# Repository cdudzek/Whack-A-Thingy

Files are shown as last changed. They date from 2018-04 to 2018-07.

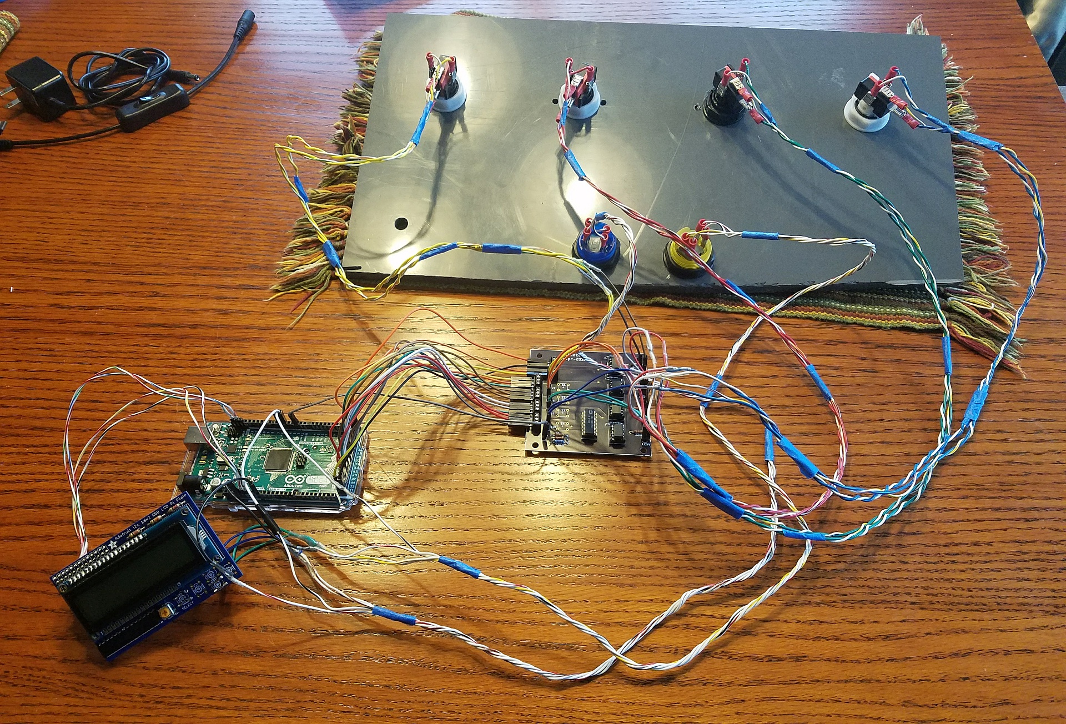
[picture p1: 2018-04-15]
Photos/Test_Wired.jpg

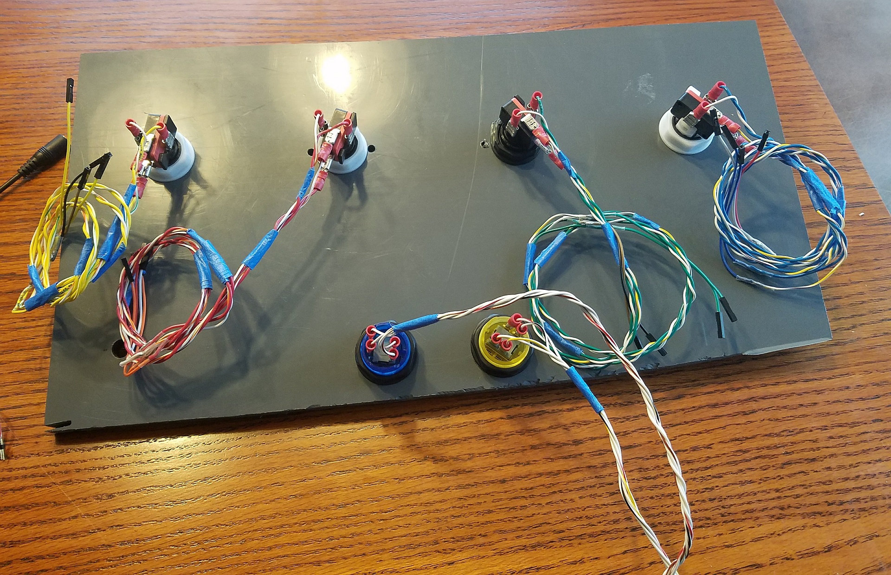
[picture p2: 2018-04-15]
Photos/Test_Buttons.jpg

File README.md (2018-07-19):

# Whack-A-Thingy
Whack-A-Thingy Multi-Gameboard

## Introduction
Whack-A-Thingy is a multi-game hardware and software platform built on an Arduino Mega 2560 controller.

This GitHub repo is a work in progress, as I am currently building the first game board as we speak. Photos, assembly guide, and gameplay will be added when available.

### Game Board
The gameboard consists of the following features:
* Arduino Mega 2560 controller
* RGB-Backlit LCD 16x2 display for menus, messages, and scores
* Two 30mm arcade buttons for menu controls (Select/Start)
* Eight 100mm colored LED-backlit arcade buttons for game targets
* Custom designed PCB to connect target buttons with Arduino controller
* Wooden base frame

### Games Included
* Whack-A-Thingy - Whack-A-Mole clone using up to 8 target buttons, with selectable speed/difficulty
* Simon Sez - Simon Says clone using up to 8 target buttons. The game runs until you get one wrong!
* Reaction Time - See how fast you can hit the button after it lights. Selectable up to 8 target buttons to increase the difficulty.
* Button Test - Check that all buttons can light up, can respond to hardware interrupts, and can respond to hardware polling

## Game Board Design
All hardware, software, and electronics used to create the board are (or soon will be) included in the repository.

The [Bill of Materials](https://github.com/cdudzek/Whack-A-Thingy/blob/master/Documents/Bill%20of%20Materials%20with%20Costs.xlsx) lists most of the electronics and hardware used in the build. The total cost of the build (not including some power tools and soldering equipment) was less than US$300. Many thanks to Adafruit for their awesome part selection at cheap prices!

### Arduino Mega and Source Code
The GameBoard folder contains all of the Arduino source files to build the game. 

The size of the code, memory footprint, and required I/Os for all of the game buttons required the use of an Arduino Mega controller (instead of an Uno-compatible). It is possible the game could be adpated to other controllers or platforms, but this is the only one I have tested with. 

#### Prerequisites
* The [Adafruit RGB LCD Library](https://github.com/adafruit/Adafruit-RGB-LCD-Shield-Library) for Arduino is required to communicate with the [I2C RGB LCD Shield for Arduinos](https://www.adafruit.com/product/716).

### Physical Board Design
The game board and components were designed in Solidworks. The CAD folder contains the original Solidworks models and assembly, as well as standard STEP files. The PDF file shows the components and assemblies.

### Electronics
The project design includes a custom-designed circuit board to interface from the Arduino to the big target buttons. The board was designed in Fritzing, and includes all of the necessary files to send the board out for fabrication. 

Each PCB controls 4 target buttons, so 2 are used for the 8 total game buttons. The price to have 3 boards fabricated with [OSHPark](https://oshpark.com/) was less than US$50.

I will be creating a Fritzing model for the custom PCBs, and plan to provide a full Fritzing assembly including the Arduino, custom PCBs, buttons, and all wiring. 

## License

This project is licensed under the Apache 2.0 License - see the [LICENSE](LICENSE) file for details

## Acknowledgments
This project is 100% custom designed (hardware, software, and electronics), but I got the original idea from the [Whac-A-Mole](https://www.hackster.io/WT040/whac-a-mole-button-edition-a2d391) project on [Hackster.io](https://hackster.io).

I would like to give a shout out to the awesome folks at [Adafruit](https://www.adafruit.com/) for their awesome product selection (including the massive [100mm arcade buttons](https://www.adafruit.com/product/1185)!), tutorials, code libraries and examples, and everything else they do. They are an inspiration. (I am in no way affiliated with Adafruit, just a very happy repeat customer.)

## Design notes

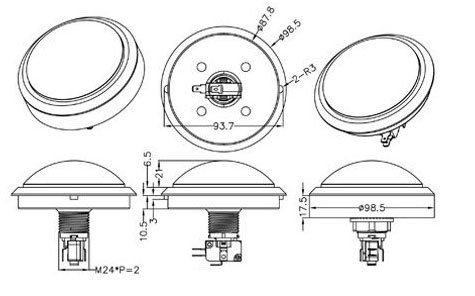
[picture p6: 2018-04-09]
Documents/Specifications/100mm Button Adafruit#1185.jpg

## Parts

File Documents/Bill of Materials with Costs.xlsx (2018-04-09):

Game Board
Bill of Materials with costs
Quantities per total project
Description | Vendor | Vendor P/N | US$ each | Qty | Ext. Price
0.1" Pitch Terminal Block, 2 pin | Adafruit | 2138 | $0.86 | 4 | $3.44
0.1" Pitch Terminal Block, 3 pin | Adafruit | 2136 | $1.13 | 8 | $9.04
100mm Arcade Button, Blue | Adafruit | 1189 | $9.95 | 2 | $19.90
100mm Arcade Button, Green | Adafruit | 1188 | $9.95 | 2 | $19.90
100mm Arcade Button, Red | Adafruit | 1185 | $9.95 | 2 | $19.90
100mm Arcade Button, Yellow | Adafruit | 1186 | $9.95 | 2 | $19.90
14-Pin DIP socket | Digikey | A401-ND | $1.56 | 2 | $3.12
2-Input AND Gate | Digikey | 296-1606-5-ND | $0.47 | 2 | $0.94
30mm Arcade Button, Blue | Adafruit | 3490 | $2.50 | 1 | $2.50
30mm Arcade Button, Yellow | Adafruit | 3488 | $2.50 | 1 | $2.50
8-Pin DIP socket | Digikey | A120347-ND | $0.16 | 8 | $1.28
9V 1000mA Power Adapter | Adafruit | 63 | $6.95 | 1 | $6.95
Arduino Mega 2560 Rev 3 | Arduino.cc | A000067 | $38.50 | 1 | $38.50
DC Power Cable 2.1mm | Adafruit | 743 | $2.50 | 1 | $2.50
Fabricated PC Boards, 80x80mm, Order/3 | OSHPark | Custom Order | $49.60 | 1 | $49.60
In-line Power Switch | Adafruit | 1125 | $2.50 | 1 | $2.50
Male Break-Away Pins, 1x36, Pack/10 | Adafruit | 392 | $4.95 | 1 | $4.95
Mega Protoshield | Adafruit | 192 | $14.95 | 1 | $14.95
Optoisolator | Digikey | 6N139-ND | $1.46 | 8 | $11.67
Panel Mount 2.1mm DC Barrel Jack | Adafruit | 610 | $2.95 | 1 | $2.95
Panel Mount USB-B Cable | Adafruit | 907 | $3.95 | 1 | $3.95
Piezo Buzzer with mount and wires | Adafruit | 1739 | $0.95 | 1 | $0.95
Resistor 10k 5% | Digikey | 10KQBK-ND | $0.06 | 10 | $0.59
Resistor 220R 5% | Digikey | 220QBK-ND | $0.06 | 12 | $0.71
RGB LCD + Keypad kit | Adafruit | 1109 | $24.95 | 1 | $24.95
Tactile Button Switch, Pack/20 | Adafruit | 367 | $2.50 | 1 | $2.50
Various LEDs (for testing and customization) | Adafruit | 300 | $8.00 | 1 | $8.00
Total |  | 27 |  |  | $278.64
Items not listed:
Jumper and interconnect wires
Crimp connectors for switches and lights
Wood, Acrylic or other Game Board frame and Legs
Soldering iron and other solder tools
Wire strippers and other hand tools
Generic USB A-B cables for Arduino
Screws and other assembly and mounting hardware
Digital Multimeter and other test tools
Tools for cutting/finishing frame pieces

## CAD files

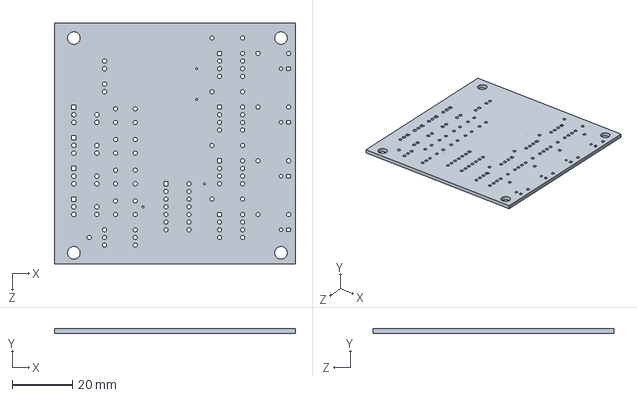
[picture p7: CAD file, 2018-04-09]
Fritzing/Target PCB/PCB_04-02-2018.SLDPRT
79.9 x 1.60 x 79.9 mm

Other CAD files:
Fritzing/Target PCB/Target4x_PCB_04-02-2018 v1.iges
Fritzing/Target PCB/PCB_04-02-2018.IGS

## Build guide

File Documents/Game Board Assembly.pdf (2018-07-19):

# Game Board Assembly

14 April 2018, Chad Dudzek

## Test Assembly

On 14 April I assembled the game board for testing on a temporary panel. It included four of the eight target buttons, the two menu buttons, one of the two custom circuit boards, the Arduino Mega controller, and the RGB LCD panel.

See the videos in the repository for the first power-on and the button test. The select/start buttons were attached to the wrong Arduino pins, so the yellow Select button did not light up on the first power-up.

Please note that in the video the 100mm buttons are not very bright because I was only pushing 5V from the Arduino through the LEDs, which are rated to 12V. On the final board assembly I will pull 9V directly from the power supply for those lights instead of powering them through the Arduino pins; this will also reduce the power draw through the Arduino board.

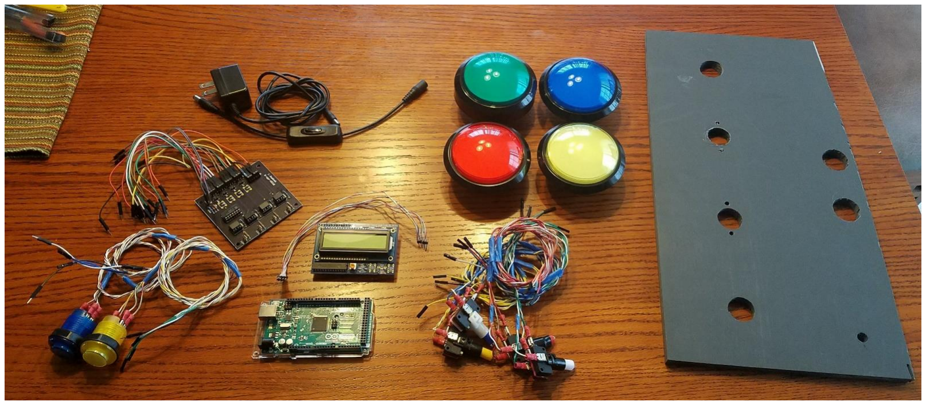
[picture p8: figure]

## Parts List

Arduino Mega 2560 Rev 3

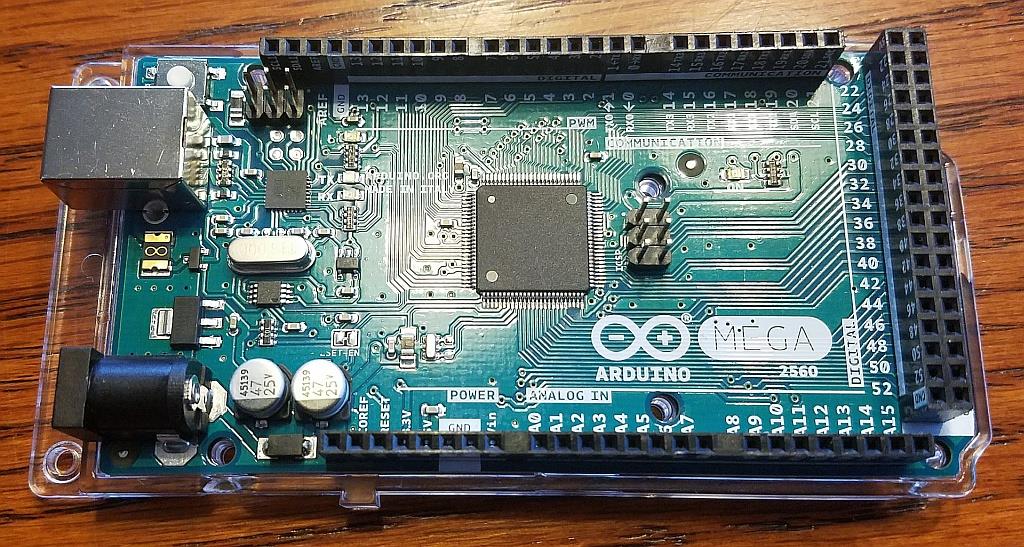
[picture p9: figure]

One of the 100mm target buttons with a switch and light attached and wired

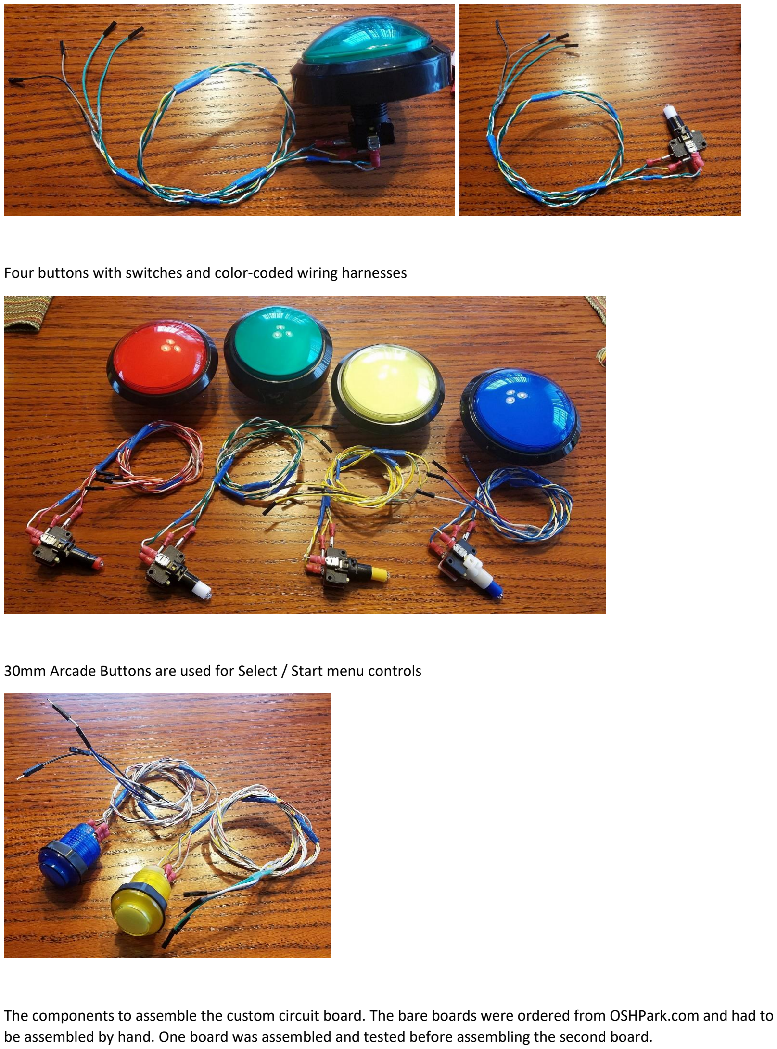
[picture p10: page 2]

Four buttons with switches and color-coded wiring harnesses

30mm Arcade Buttons are used for Select / Start menu controls

The components to assemble the custom circuit board. The bare boards were ordered from OSHPark.com and had to be assembled by hand. One board was assembled and tested before assembling the second board.

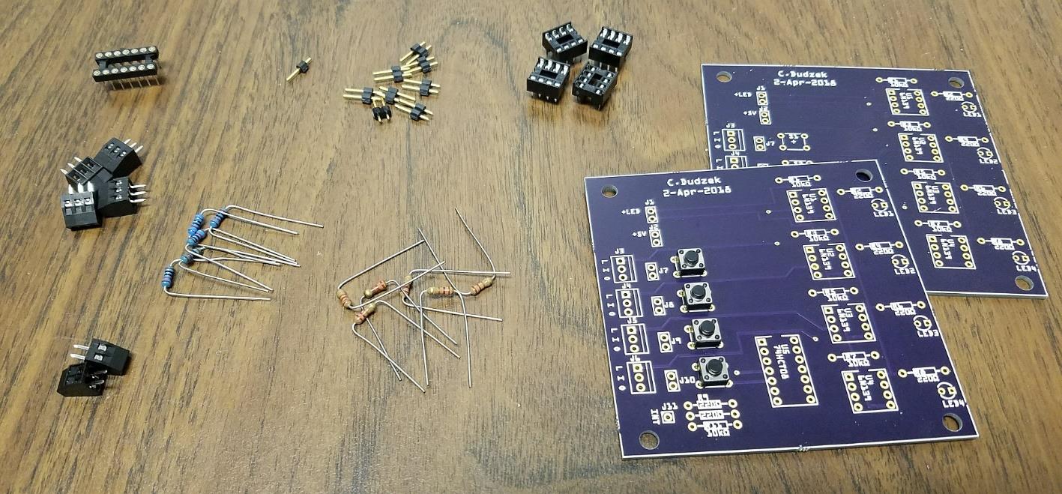
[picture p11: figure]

The assembled board, and with the cables attached which connect to the Arduino. For the test build I used a 74HCT21 (4-input AND gate) in U5 instead of the 74HCT08 (2x 2-input AND gate). The rest of the circuit is the same, but the 74HCT21 combines all 4 inputs into a single output, and can be used as a drop-in replacement in this board with no other changes.

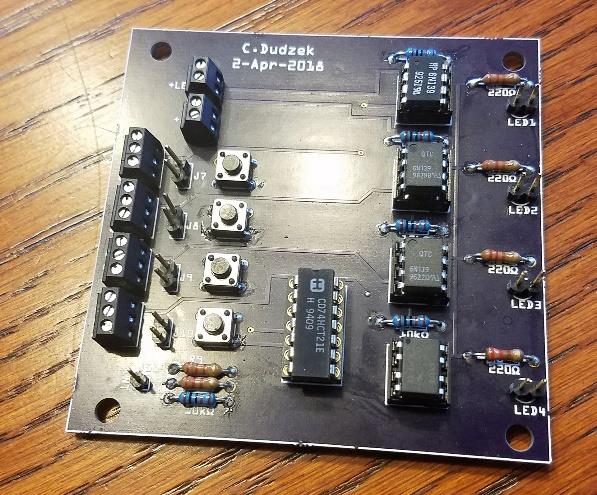
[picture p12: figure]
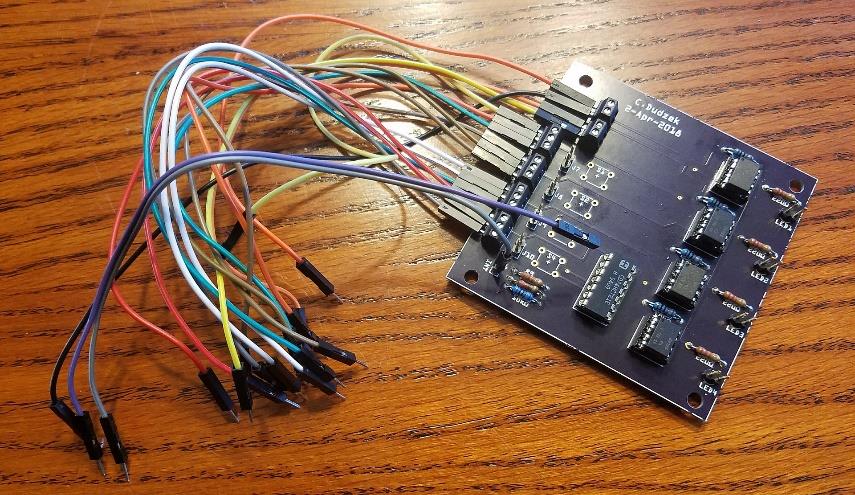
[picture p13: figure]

After soldering up the first board and testing it, I discovered I had a trace on the wrong side and it shorted to a 5V input. The trace for U4 Pin 3 (grounds to enable LED4) crossed the trace to U5 Pin 14, which is the +5V supply. Whoops! The trace had to be cut on the bottom of the board where the traces intersected, and a jumper wire soldered from J6 Pin 1 to U4 Pin 3.

TODO: Add photo of jumper wire

A 9V/1A power supply and switch from Adafruit are used to power the whole game board.

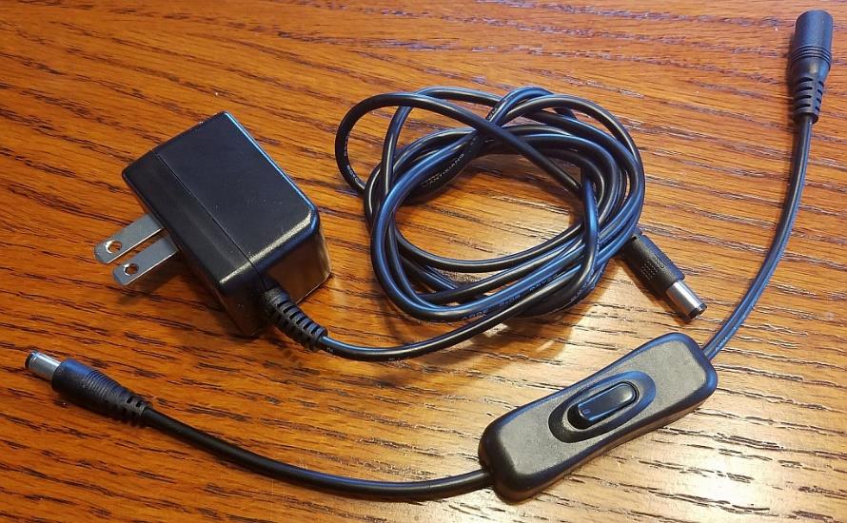
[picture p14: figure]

The Adafruit RGB LCD Pi Plate. This is designed to attach to the top of a Raspberry Pi, but a wiring harness was created to attach to the Arduino. Only the 5VDC, Ground, and I2C wires are needed.

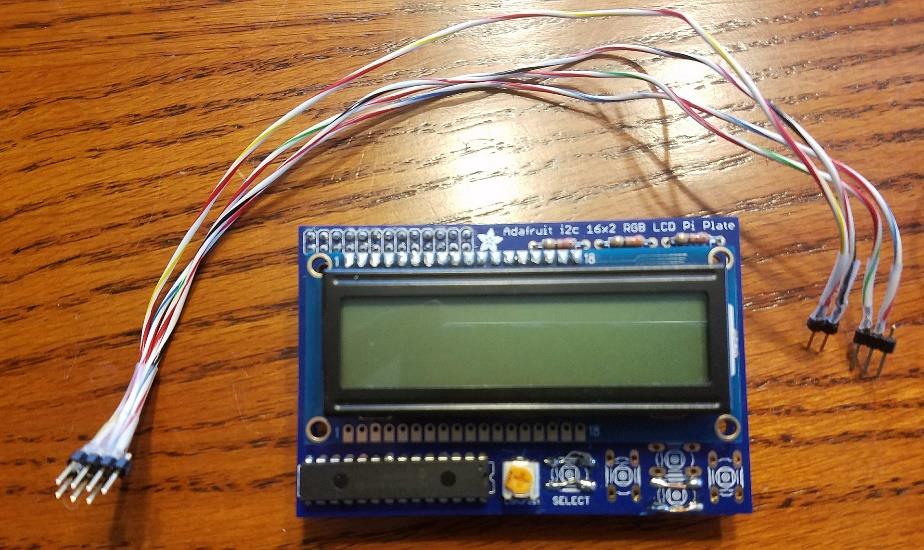
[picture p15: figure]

A test panel was used to mount all of the control and target buttons for initial testing. One inch holes were drilled for the four target buttons and 1-1/8” holes were drilled for the 30mm control buttons. The LCD, Arduino, and circuit boards were not mounted for testing.

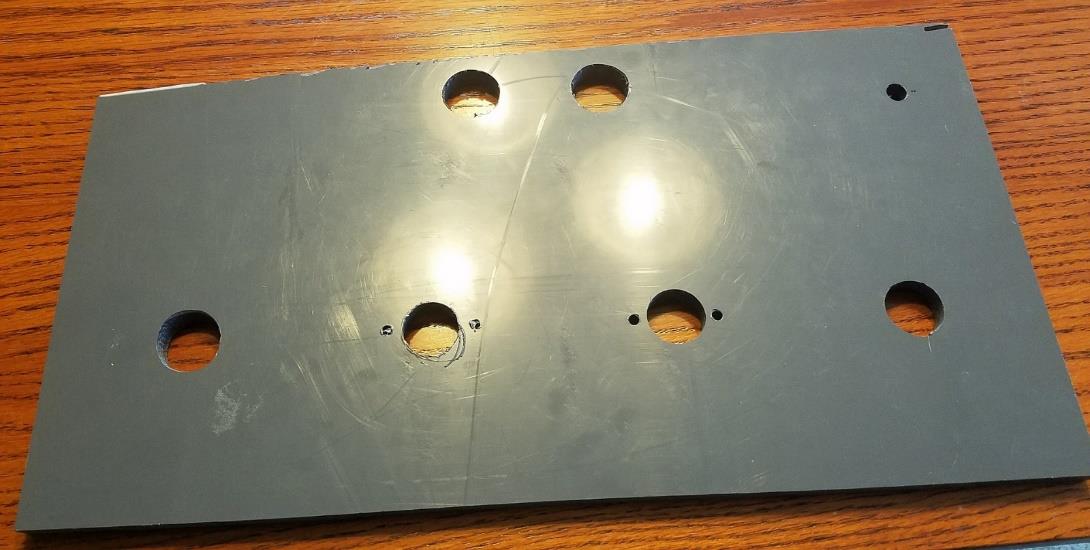
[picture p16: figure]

With the buttons mounted

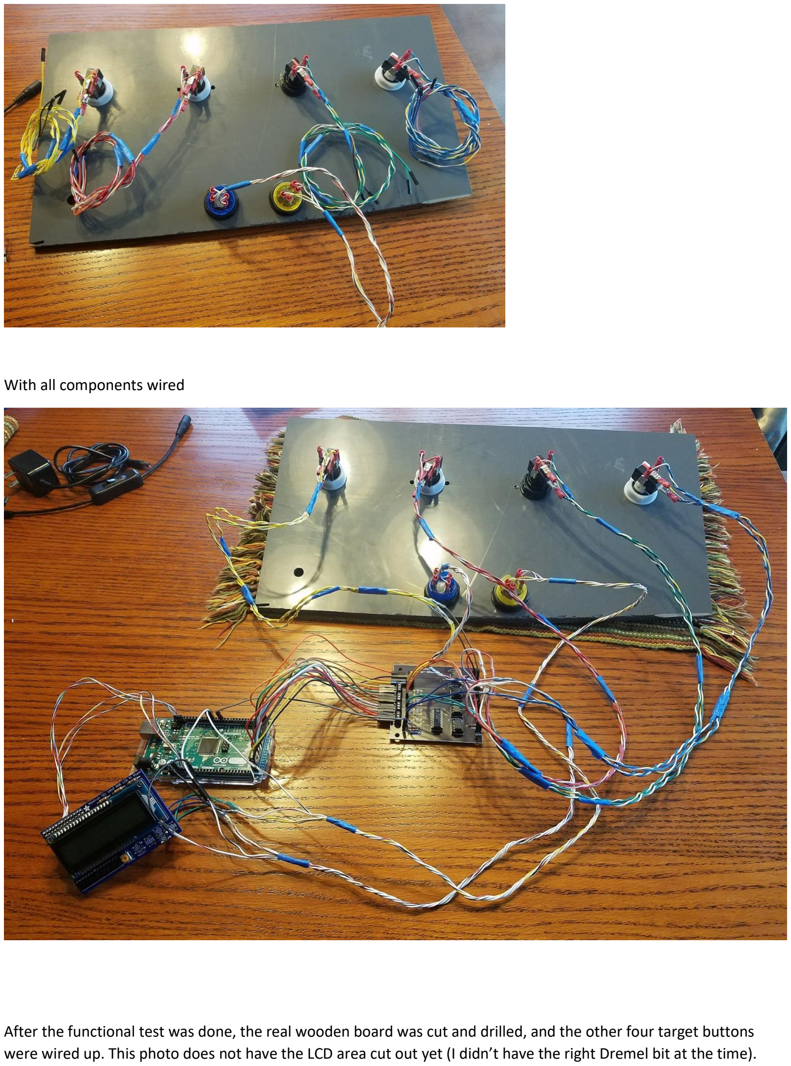
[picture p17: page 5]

With all components wired

After the functional test was done, the real wooden board was cut and drilled, and the other four target buttons were wired up. This photo does not have the LCD area cut out yet (I didn’t have the right Dremel bit at the time).

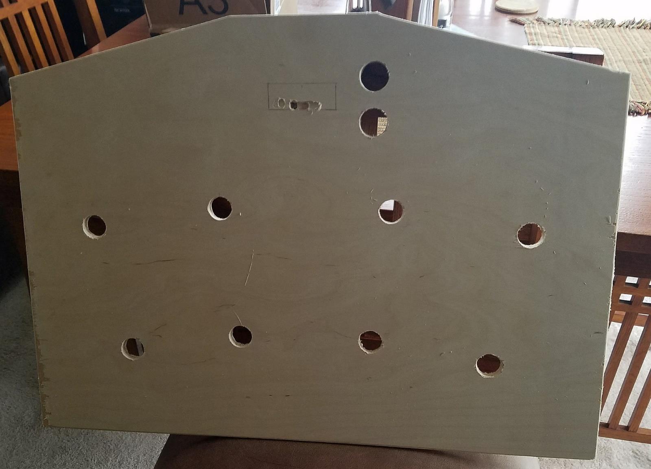
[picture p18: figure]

The board is a ½” (12.5mm) layered birch wood. I bought the green 100mm target buttons from Adafruit, and I was able to mount the button on the board with the extra backing disc to have a solid-looking body. However, the other colored buttons were bought on Amazon (only because they were out of stock at Adafruit) and were not long enough to fit with the backing disc so they had to be mounted without it. The product images and dimension drawing on Amazon were IDENTICAL to the ones on Adafruit, but the buttons were indeed not the same product. The shaft length was not specified on either site, so I do not know which one was technically correct.

TODO: Side view of board with button threads

## Wiring

This is the top view of the PC Board (with the corrected trace). All components are labeled, including the resistor values. Yellow lines are traces on the top of the board, and orange lines are traces on the bottom of the board.

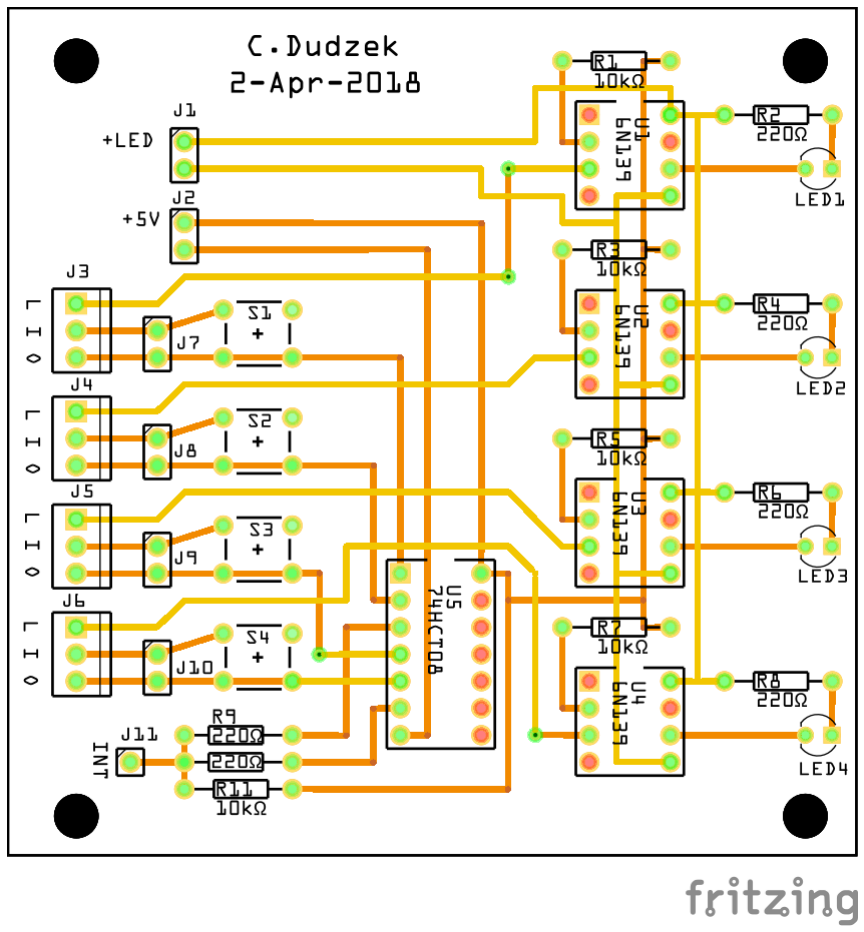
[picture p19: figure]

Connector J1 is input power for the target button LEDs. The 100mm buttons from Adafruit are 12V capable, and the U1-U4 chips are optoisolators (they work like relays) to allow the 12V to be used without frying your Arduino board. Pin 1 is up to +12V, and pin 2 is ground.

Chips U1-U4 will ground pin 6 to turn on the LEDs. Two-pin headers are soldered into the LED1-LED4 pins instead of LEDs so the target button LEDs can be attached.

Connector J2 is the +5V power for the ICs. U5 is powered directly on pin 14. Resistors R1, R3, R5, and R7 are used to drop the voltage to 1.4V for the optoisolator triggers on pin 2 of each chip.

Connectors J3-J6 are the controls for each target, which connect to the Arduino. Note that connectors have the pins labeled L-I-O next to each connector. These are “LED on”, “Switch Input”, and “Switch Output”.

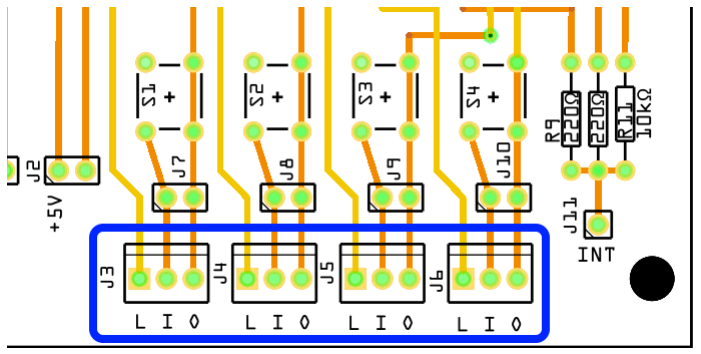
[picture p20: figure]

When the LED (L) pin on each connector is grounded, the LED for that target will be lit.

Connectors J7-J10 are headers to the target button switches. They short connect the Input (I) and Output (O) pins of each target when pressed. Switches S1-S4 are entirely optional to populate. They are sized for the 6x6mm tactile switches from Adafruit. They are handy for testing the circuit without having to wire up the 100mm target buttons but are not required for proper game operation.

Chip U5 is the 4-input AND gate to output an interrupt signal when an enabled target button is pressed. When an Input (I) pin on J3-J6 is grounded, that target button is enabled. The AND gate isolates the buttons from each other, so only an enabled button can trigger the interrupt or be read from the Output (O) pin.

Pin J11 is the interrupt pin to signal the Arduino that an enabled target has been pressed. This is used especially for the Whack-A-Mole game to instantly signal the program that an active mole has been whacked.

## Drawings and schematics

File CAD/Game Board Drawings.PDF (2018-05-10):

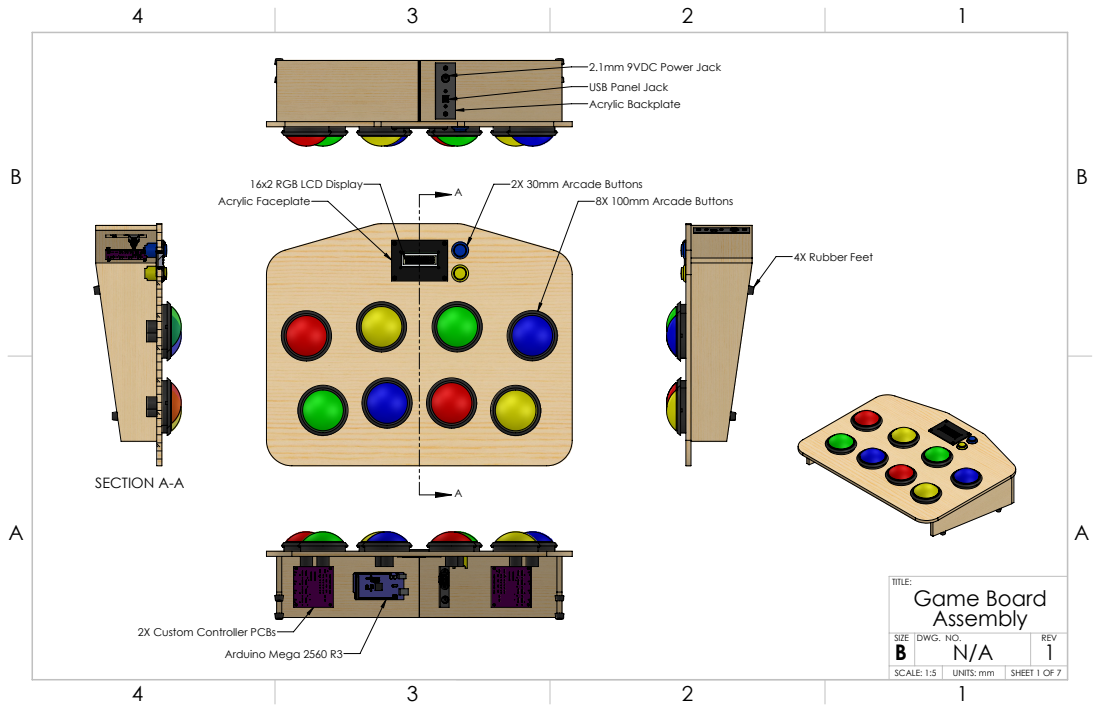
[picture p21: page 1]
16x2 RGB LCD Display; 2X 30mm Arcade Buttons; Acrylic Faceplate; 8X 100mm Arcade Buttons; Arduino Mega 2560 R3; SECTION A-A; 4X Rubber Feet; Game Board

2.1mm 9VDC Power Jack
USB Panel Jack
Acrylic Backplate

2X Custom Controller PCBs

SIZE B | DWG. NO. N/A | REV 1

SCALE: 1:5 | UNITS: mm | SHEET 1 OF 7

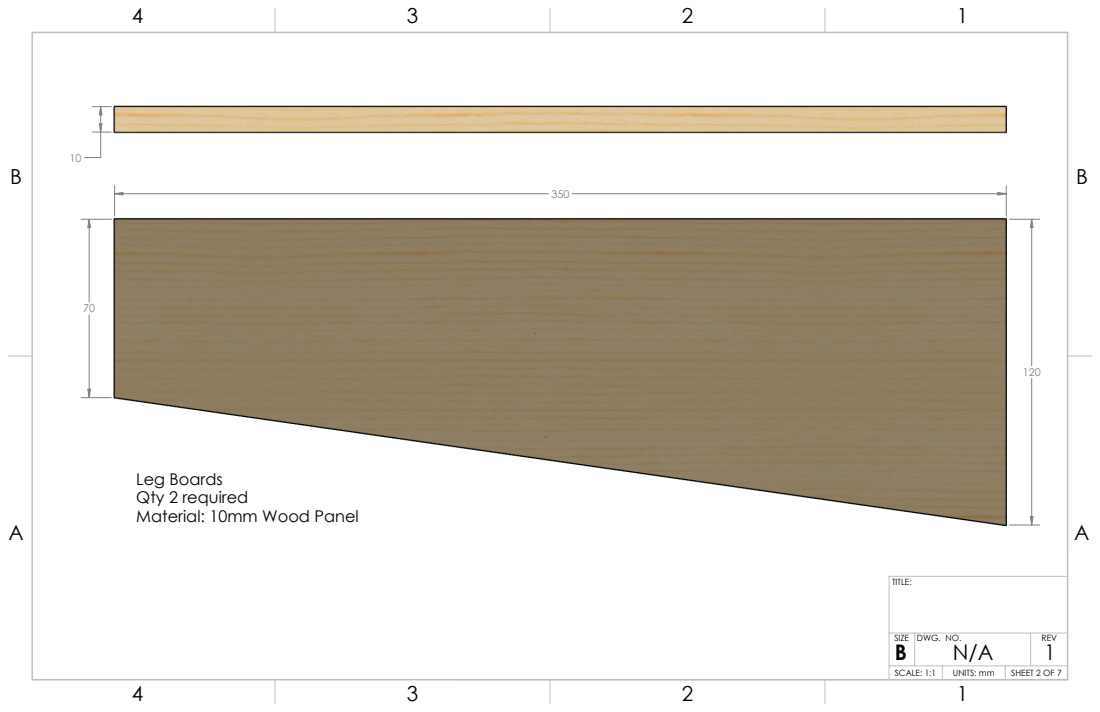
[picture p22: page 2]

Leg Boards
Qty 2 required
Material: 10mm Wood Panel

SIZE B | DWG. NO. N/A | REV 1

SCALE: 1:1 | | SHEET 2 OF 7

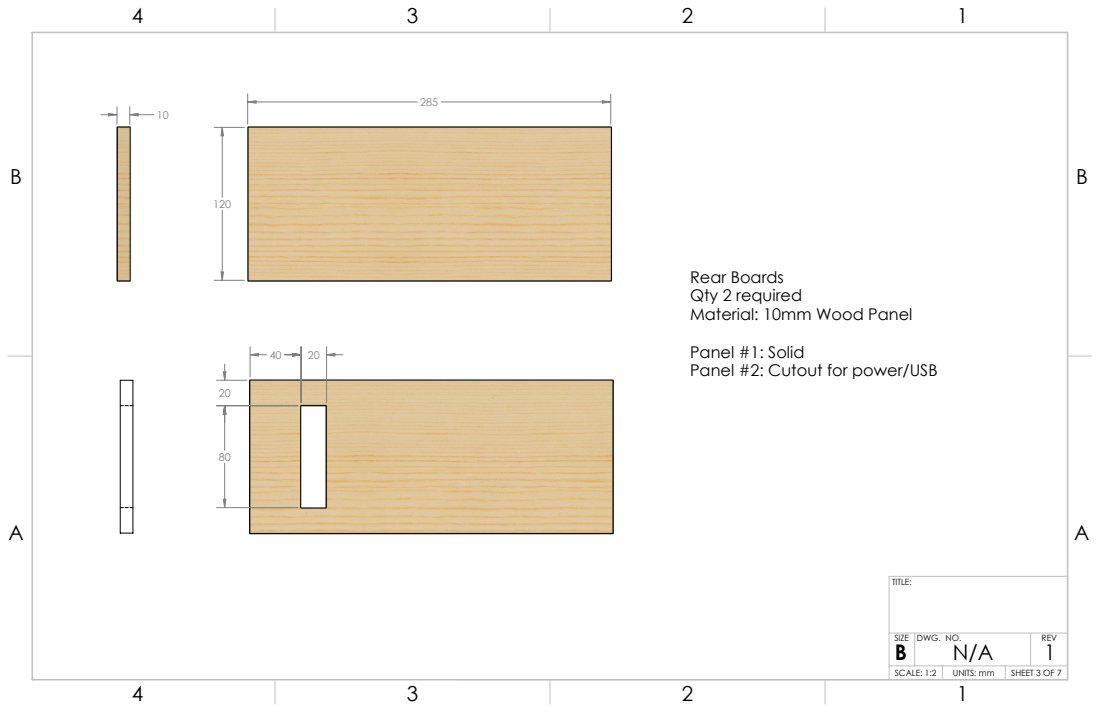
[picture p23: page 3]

Rear Boards
Qty 2 required
Material: 10mm Wood Panel
Panel #1: Solid
Panel #2: Cutout for power/USB

SIZE B | DWG. NO. N/A | REV 1

SCALE: 1:2 | | SHEET 3 OF 7

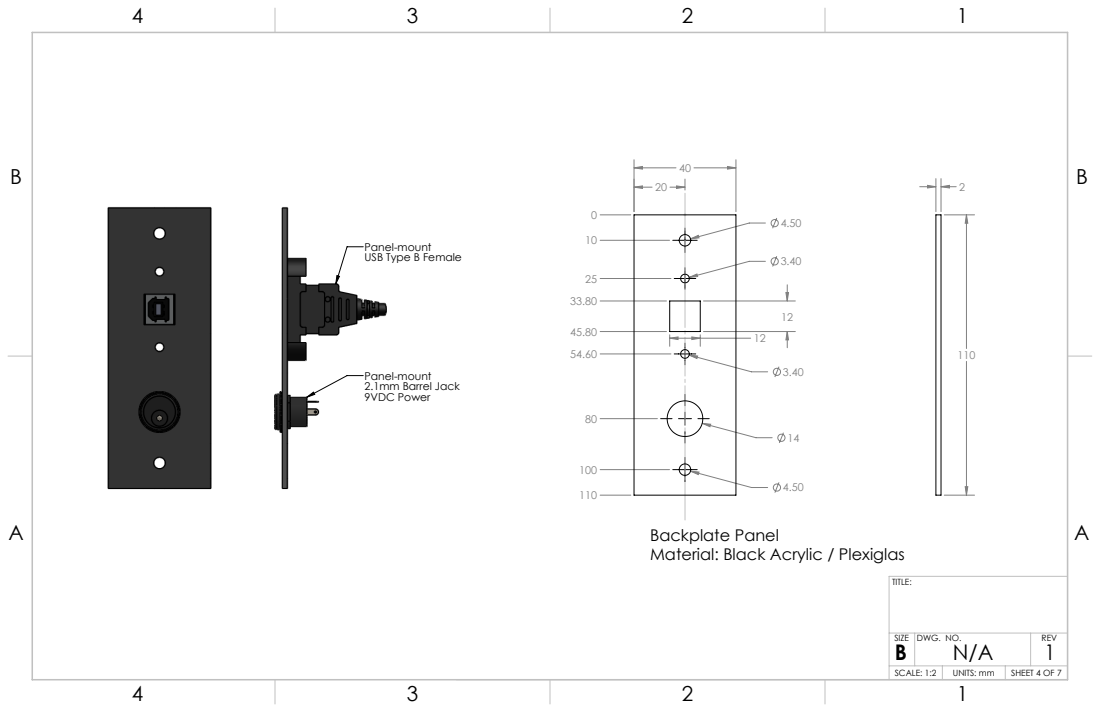
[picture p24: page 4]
2.1mm Barrel Jack 9VDC Power; DWG. NO.; REV

Panel-mount
USB Type B Female

Backplate Panel
Material: Black Acrylic / Plexiglas

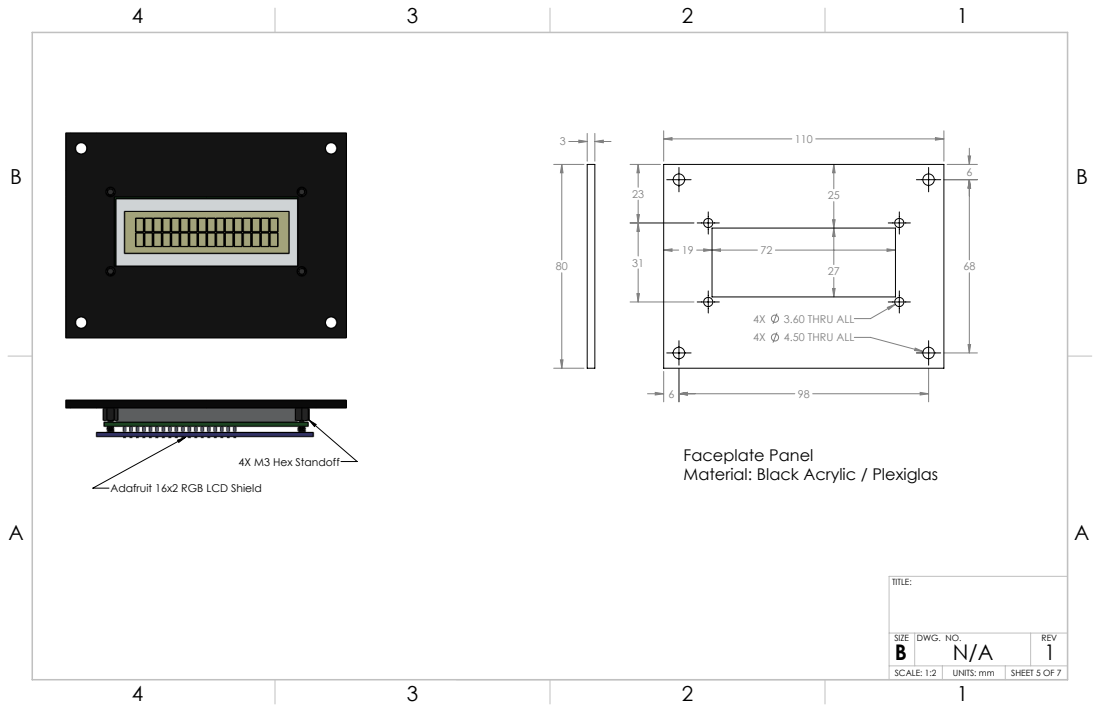
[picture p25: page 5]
4X M3 Hex Standoff; 3.60 THRU ALL; 4.50 THRU ALL; DWG. NO.; REV

Faceplate Panel
Material: Black Acrylic / Plexiglas

Adafruit 16x2 RGB LCD Shield

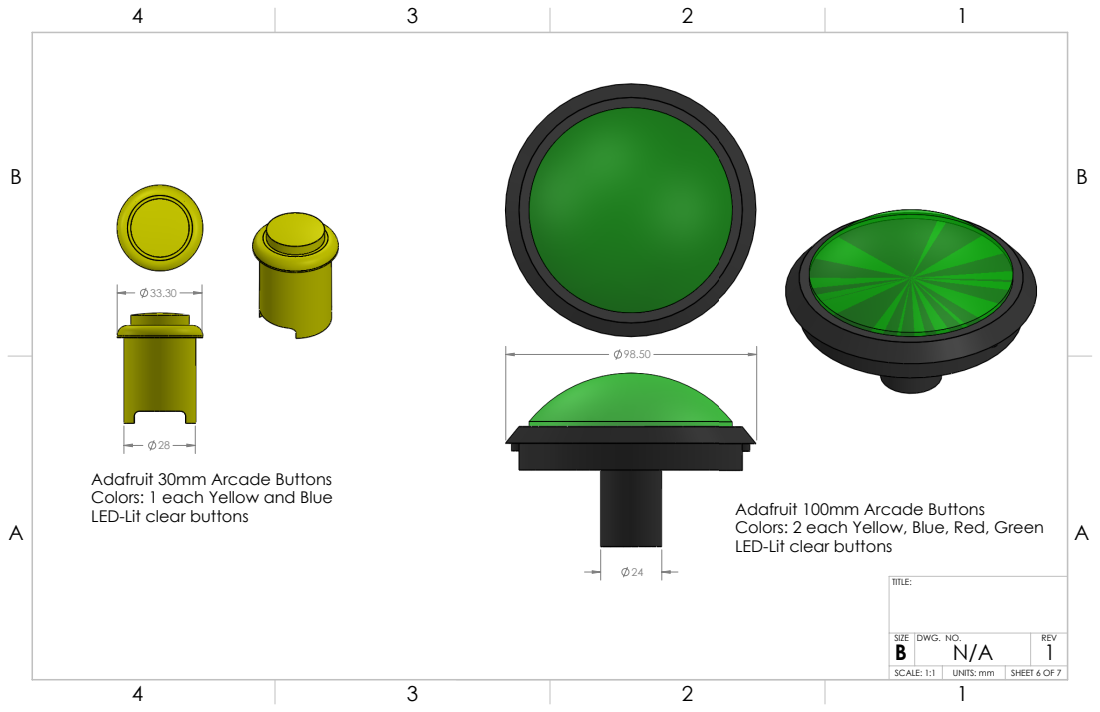
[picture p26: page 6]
LED-Lit clear buttons; Adafruit 100mm Arcade Buttons

Adafruit 30mm Arcade Buttons
Colors: 1 each Yellow and Blue

Colors: 2 each Yellow, Blue, Red, Green
LED-Lit clear buttons

SIZE B | DWG. NO. N/A | REV 1

SCALE: 1:1 | | SHEET 6 OF 7

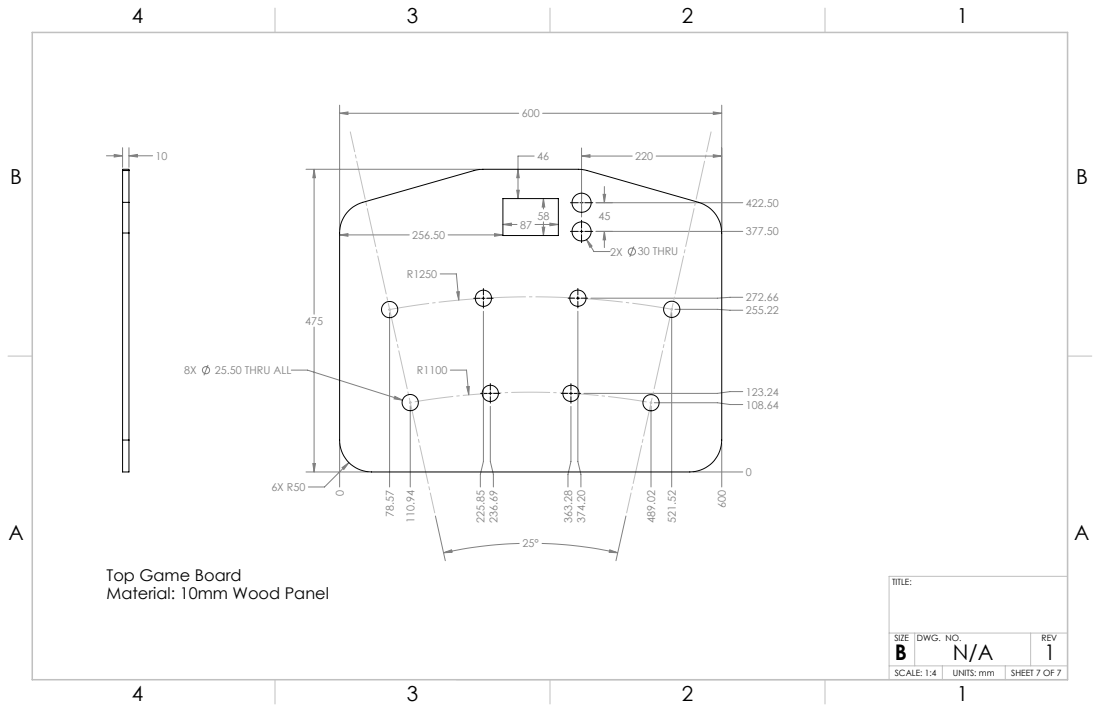
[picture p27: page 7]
2X 30 THRU; 25.50 THRU ALL

Top Game Board
Material: 10mm Wood Panel

SIZE B | DWG. NO. N/A | REV 1

SCALE: 1:4 | | SHEET 7 OF 7

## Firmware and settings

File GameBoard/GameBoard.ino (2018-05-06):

#include <Adafruit_RGBLCDShield.h>
#include "GameBoard.h"

Adafruit_RGBLCDShield lcd = Adafruit_RGBLCDShield();
uint8_t lcdcolor;
GameType game;

/////////////////////////////////////////
// Setup
void setup() {
  // Setup Serial
  Serial.begin(9600);

  // Setup LCD display
  lcd.begin(16, 2);
  lcd.createChar(FROWNIE, (uint8_t*)frownie);
  lcd.createChar(SMILEY, (uint8_t*)smiley);
  lcd.noBlink();
  lcd.noCursor();
  lcdcolor = WHITE;
  lcd.setBacklight(lcdcolor);
  lcd.clear();
  lcd.home();
  lcd.print(s_AppTitle);
  //delay(2000);
  lcd.setCursor(0, 1);

  // Setup I/O
  for (int t = 0; t < NumTargets; t++) {
    pinMode(Targets[t].LedEnable, OUTPUT);
    pinMode(Targets[t].SwitchEnable, OUTPUT);
    pinMode(Targets[t].SwitchRead, INPUT_PULLUP);
    digitalWrite(Targets[t].LedEnable, HIGH); 
    digitalWrite(Targets[t].SwitchEnable, HIGH); 
  }
  // Select/Start buttons
  pinMode(LED_START, OUTPUT);
  pinMode(LED_SELECT, OUTPUT);

  // Test all lights
  SweepLights();

  // Control buttons lit
  digitalWrite(LED_START, LOW);
  digitalWrite(LED_SELECT, LOW);

  // Setup Game
  game = (GameType)0;

}

/////////////////////////////////////////
// Loop
void loop() {
  lcd.home();
  lcd.print(s_SelectGame);
  lcd.setCursor(0, 1);
  lcd.print(NameOfTheGame[(int)game]);
      
  uint8_t buttons = lcd.readButtons();

  if (buttons) {
    if (buttons & BUTTON_SELECT) {
      LaunchGame(game, lcd);
      lcd.clear();
      delay(DEBOUNCE);
      digitalWrite(LED_START, LOW);
      digitalWrite(LED_SELECT, LOW);
    }

    // Choose Game
    else if (buttons & BUTTON_UP) {
      game = PrevGame(game);
      delay(DEBOUNCE);
      lcd.setCursor(0, 1);
      lcd.print(NameOfTheGame[(int)game]);
    }
    else if (buttons & BUTTON_DOWN) {
      game = NextGame(game);
      delay(DEBOUNCE);
      lcd.setCursor(0, 1);
      lcd.print(NameOfTheGame[(int)game]);
    }

    // Change Color
    else if (buttons & BUTTON_LEFT) {
      lcdcolor = ColorScrollDown(lcdcolor);
      lcd.setBacklight(lcdcolor);
    }
    else if (buttons & BUTTON_RIGHT) {
      lcdcolor = ColorScrollUp(lcdcolor);
      lcd.setBacklight(lcdcolor);
    }
    
  }
}

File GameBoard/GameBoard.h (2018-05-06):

#ifndef _GAMEBOARD_H_
#define _GAMEBOARD_H_

#include <Arduino.h>
#include <Adafruit_RGBLCDShield.h>
#include "ButtonTest.h"
#include "Reaction.h"
#include "SimonSez.h"
#include "Whacker.h"

/////////////////////////////////////////
// Message Strings (pad to 16 chars)
//                          
const String s_Blank        = "                ";
const String s_AppTitle     = "Game Board v0.2 ";
const String s_SelectGame   = "Select Game:    ";
const String s_SelectLevel  = "Select Level:   ";
const String s_Exit         = "Exit to MainMenu";
const String s_AnyKey       = "Press any button";
const String s_Ready        = "Ready           ";
const String s_NumButtons   = "# of Buttons:   ";
const String s_UsingButtons = "Using x buttons ";
const String s_Cheater      = "CHEATER!        ";
const String s_ButtonDown   = "Button is held  ";
const String s_CountDown    = "Ready in        ";
const String s_Score        = "Score           ";
// Games
const String sg_Simon       = "Simon Sez       ";
const String sg_Whacker     = "Whack-A-Thingy  ";
const String sg_Test        = "Button Test     ";
const String sg_React       = "Reaction Time   ";
// List of games (match order to enum GameType below)
const String NameOfTheGame[] = {
  sg_Whacker,
  sg_Simon,
  sg_React,
  sg_Test,
  s_Blank         // No game (gINVALID / wrap end of list)
};

/////////////////////////////////////////
// Game Options
enum GameType { WHACKER, SIMON, REACTION, HITTEST, gINVALID };      // Match order to NameOfTheGame[] above
GameType NextGame(GameType gt);   // Scroll game list
GameType PrevGame(GameType gt);   // Scroll game list
bool LaunchGame(GameType gt, Adafruit_RGBLCDShield _lcd);     // Launch the selected game

/////////////////////////////////////////
// Backlight and LED colors
#define BLACK 0x0
#define RED 0x1
#define GREEN 0x2
#define YELLOW 0x3
#define BLUE 0x4
#define VIOLET 0x5
#define TEAL 0x6
#define WHITE 0x7

/////////////////////////////////////////
// Scroll Backlight Colors
uint8_t ColorScrollUp(uint8_t color);
uint8_t ColorScrollDown(uint8_t color);

/////////////////////////////////////////
// Buttons and Interrupts
//
// Mega Interrupts: 2, 3, 18, 19, 20, 21
// Uno Interrupts: 2, 3
//
#define DEBOUNCE   200
#define INT_PIN1   2
#define INT_PIN2   3
#define LED_START  5
#define LED_SELECT 6
uint8_t ReadAllButtons(void);     // Return bitmask of pressed target buttons
String LcdButtons(Adafruit_RGBLCDShield _lcd);  // Return string of pressed buttons on LCD
void PressAnyKey(Adafruit_RGBLCDShield _lcd);   // Pause until button is pressed
void SweepLights(void);     // Light up each button (typically on boot)
void Countdown(unsigned long ms, Adafruit_RGBLCDShield _lcd);   // Countdown timer

struct TargetPins_T {
  uint8_t LedEnable;
  uint8_t SwitchEnable;
  uint8_t SwitchRead;
  uint8_t LedColor;       // use #defined colors above
};

// Mega pinouts, lower connector:
// Even side: 22-52
// Odd side:  23-53
const TargetPins_T Targets[] = 
{
  { 29, 31, 33, YELLOW },     // Yellow 2
  { 34, 36, 38, GREEN  },     // Green 1
  { 41, 43, 45, BLUE   },     // Blue 2
  { 22, 24, 26, RED    },     // Red 1  
  { 23, 25, 27, RED    },     // Red 2  
  { 40, 42, 44, BLUE   },     // Blue 1
  { 35, 37, 39, GREEN  },     // Green 2
  { 28, 30, 32, YELLOW }      // Yellow 1
};
const size_t NumTargets = sizeof(Targets) / sizeof(TargetPins_T);

/////////////////////////////////////////
// Custom LCD symbols
#define SMILEY 0
#define FROWNIE 1
const uint8_t smiley[8] = {
  0b00000,
  0b00000,
  0b01010,
  0b00000,
  0b00000,
  0b10001,
  0b01110,
  0b00000
};
const uint8_t frownie[8] = {
  0b00000,
  0b00000,
  0b01010,
  0b00000,
  0b00000,
  0b00000,
  0b01110,
  0b10001
};


#endif // _GAMEBOARD_H_

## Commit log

2018-04-09 Add Fritzing assembly, PCB design, and components
    [Game Board with Arduino Mega.fzz, PCB_04-02-2018.IGS, PCB_04-02-2018.SLDPRT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]
2018-04-09 Initial BOM
    [Bill of Materials with Costs.xlsx]
2018-04-09 Add specs for components used in the assembly
2018-04-09 Intended physical game board design
2018-04-15 Fix overlapping trace to U4 Pin 3
    [Target 4x Rev 1.fzz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]
2018-04-15 Photos of the first assembly
2018-05-06 Add Arduino sketch
    All source files for all game modes. Compiles on Arduino Mega 2560.
2018-05-07 Resolve issue with never-ending Whacker game. Set final score display timeouts on all games.
    [Reaction.cpp, SimonSez.cpp, Whacker.cpp]
2018-05-10 Add Game Board drawings, Solidworks CAD models, and STEP models
2018-07-19 Add extra photos and Assembly document. Minor changes to README.md.
